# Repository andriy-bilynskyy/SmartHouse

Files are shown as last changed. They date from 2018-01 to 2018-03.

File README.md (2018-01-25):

# Water leaks motinoring system

## System overview
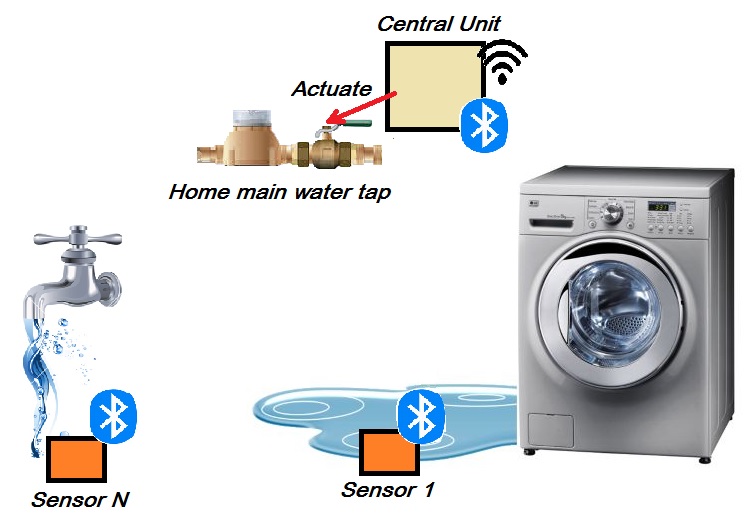
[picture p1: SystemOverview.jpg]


## Features
* Easy integration: The system can be easy integrated into existing environment, no additional wires and pipes replacements.
* Flexible configuration: The system can support different count of water leak sensors, it's easy to add or remove water leak sensor during runtime operation.
* User friendly interface: The system is using simple web interface for configuration and monitoring.
* Non-volatile operation: The system can work without electricity due to backup power supply.
* Low power consumption: Due to used technologies the system use low electricity
* No high voltage: All system components are working with safe 12 volts power supply.
* New technologies: BLE sensors, WI-FI access, WEB user interface.

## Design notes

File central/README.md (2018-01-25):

## Central unit

### HW specification

|Item |Type |Count|Seller link |
|---|---|-----|---|
|MCU unit |Raspberry Pi 3 model B |1 |[original raspberry pi 3 model b](https://www.aliexpress.com/item/In-stock-2015-New-Original-Raspberry-Pi-2-Model-B-1GB-RAM-900Mhz-Quad-Core-ARM/32475849620.html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) |
|SD card |THN-M401S0160E2 |1 |[Toshiba Excerial Pro microSDHC](https://rozetka.com.ua/tshba_microsdhc_pro_16gb_c10_m401s0160e2/p15933949/) |
|Motor driver |board module L298 |1 |[L298N motor driver](https://www.aliexpress.com/item/Special-promotions-5pcs-lot-L298N-motor-driver-board-module-L298-for-arduino-stepper-motor-smart-car/1827893830.html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) |
|5V DC-DC |USB Charge DC-DC Step-down |1 |[USB Charge DC-DC Step-down](https://www.aliexpress.com/item/DC-6V-40V-To-5V-3A-Double-USB-Charge-DC-DC-Step-down-Converter-Module/32664778995.html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,searchweb201602_1_10152_10170_10065_10151_10068_10326_10084_10083_10080_10307_10082_10081_10110_10137_10111_10060_10112_10113_10155_10114_10154_10056_10055_10054_10312_10313_10059_10314_10315_100031_10099_10078_10079_10103_10073_10102_10052_10053_10142_10107_10050_10051-10052_10110,searchweb201603_3,ppcSwitch_5&btsid=f8e5297e-bf45-4b2f-9ce3-2039edf0a898&algo_expid=a3243491-fae2-42a2-a977-101cb692e6c8-0&algo_pvid=a3243491-fae2-42a2-a977-101cb692e6c8&transAbTest=ae803_3) |
|Valve actuator |Yongkang Black Color DN20/DN25|1 |[Yongkang Black Color](https://www.aliexpress.com/item/Yongkang-Black-Color-DN15-LPG-Gas-Valve-Water-Valve-for-Automatic-Shut-Off/32779379748.html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) |
|Backup PSU |Lithium Ion battery pack |1 |[Lithium Ion battery pack](https://www.aliexpress.com/item/Portable-Super-Rechargeable-Lithium-Ion-battery-pack-capacity-DC-12-V-6800-Mah-CCTV-Cam-Monitor/32692388612.html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) |
|Box |--- |1 |--- |
|Wires |--- |---  |--- |

#### HW connection
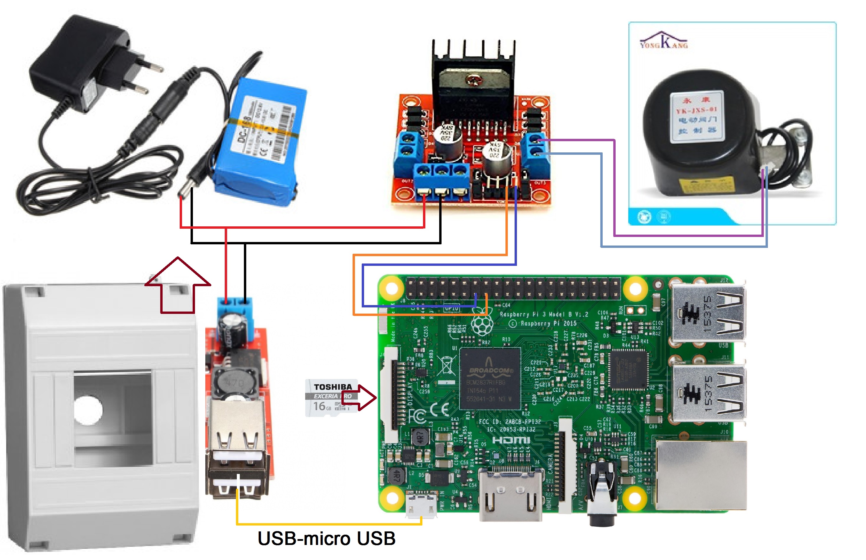
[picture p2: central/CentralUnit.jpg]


## Raspberry PI preparation
### Upgrade raspberry
    sudo apt-get update
    sudo apt-get dist-upgrade
### Setup WIFI
    sudo nano /etc/network/interfaces

    auto lo
    iface lo inet loopback

    auto wlan0
    iface wlan0 inet static
    address 192.168.0.10
    netmask 255.255.255.0
    gateway 192.168.0.1
    wpa-essid ap_name
    wpa-psk ap_pass
    
### Clone repository to home folder on Raspberry Pi
    sudo apt-get install git
    ssh-keygen -t rsa
    git clone git@github.com:andriy-bilynskyy/SmartHouse.git 
### Install Apache
    sudo apt-get install apache2
### Install SQL
    sudo apt-get install mysql-server
### Install PHP
    sudo apt-get install php5 libapache2-mod-php5 php5-mysql    
### Relocate Apache html content 
    sudo /etc/init.d/apache2 stop
    sudo rm -R html/
    sudo ln -s /home/pi/SmartHouse/central/www/ /var/www/html
    sudo /etc/init.d/apache2 start
### Install Bluetooth
    sudo apt-get install bluetooth bluez
    
### NGINX (optional instead of appache)
 
	sudo apt-get install nginx
	sudo apt-get install php5-fpm
	sudo nano /etc/nginx/sites-enabled/default

	index index.php index.html index.htm;

	# pass the PHP scripts to FastCGI server listening on 127.0.0.1:9000
	#
	location ~ \.php$ {
		include snippets/fastcgi-php.conf;

		# With php5-cgi alone:
	#       fastcgi_pass 127.0.0.1:9000;
		# With php5-fpm:
		fastcgi_pass unix:/var/run/php5-fpm.sock;
	}

	sudo /etc/init.d/nginx reload
	sudo /etc/init.d/nginx start

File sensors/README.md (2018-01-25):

## Water leak sensor ADC front-end
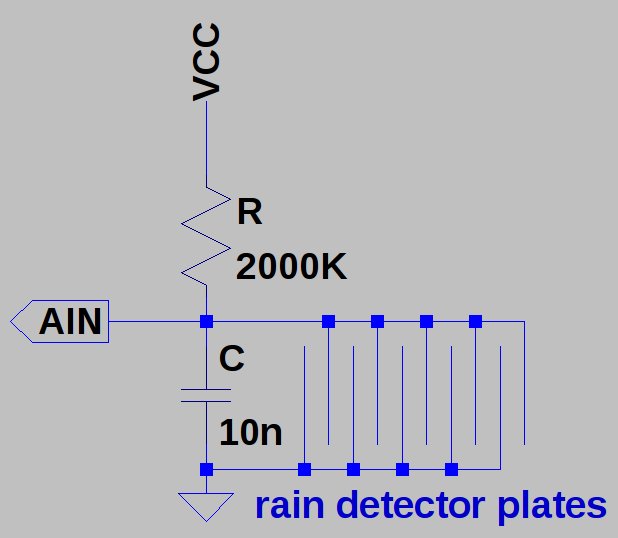
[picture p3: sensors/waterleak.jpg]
 
## Debug the system

edit the file
ble_sensors/src/sdk_config.h
	#define NRF_LOG_ENABLED 0
set value to 1

	JLinkRTTClient
	
	JLinkExe -device nrf51822 -speed 1000 -if swd
	r
	g

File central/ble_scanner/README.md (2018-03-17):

## Bluetooth low energy sensors scanner
This part of software monitors available bluetooth LE sensors.
And updates the information about them and theirs state.
#### Compile executable
source files location: *central/ble_scanner*
necessarily libraries:
- libmysqlclient-dev
- libbluetooth-dev

	make
#### Insatallation
	sudo cp ble_scanner_serv /etc/init.d/
	sudo update-rc.d ble_scanner_serv defaults
#### Usage
	sudo /etc/init.d/ble_scanner status
	sudo /etc/init.d/ble_scanner start
	sudo /etc/init.d/ble_scanner stop
	sudo /etc/init.d/ble_scanner restart

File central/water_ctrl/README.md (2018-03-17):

## Water valve control service
This part of software analyzes state of subscribed water leak sensors.
Based on this information it controls the water valve.
#### Compile executable
source files location: *central/water_valve_ctrl*
necessarily libraries:
- libmysqlclient-dev
- [Wiring Pi](http://wiringpi.com/examples/quick2wire-and-wiringpi/install-and-testing/)

	make
#### Insatallation
	sudo cp valve_ctrl_serv /etc/init.d/
	sudo update-rc.d valve_ctrl_serv defaults
#### Usage
	sudo /etc/init.d/valve_ctrl status
	sudo /etc/init.d/valve_ctrl start
	sudo /etc/init.d/valve_ctrl stop
	sudo /etc/init.d/valve_ctrl restart

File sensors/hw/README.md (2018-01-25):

[PCB manufacture](https://www.elecrow.com/10pcs-2-layer-pcb.html)

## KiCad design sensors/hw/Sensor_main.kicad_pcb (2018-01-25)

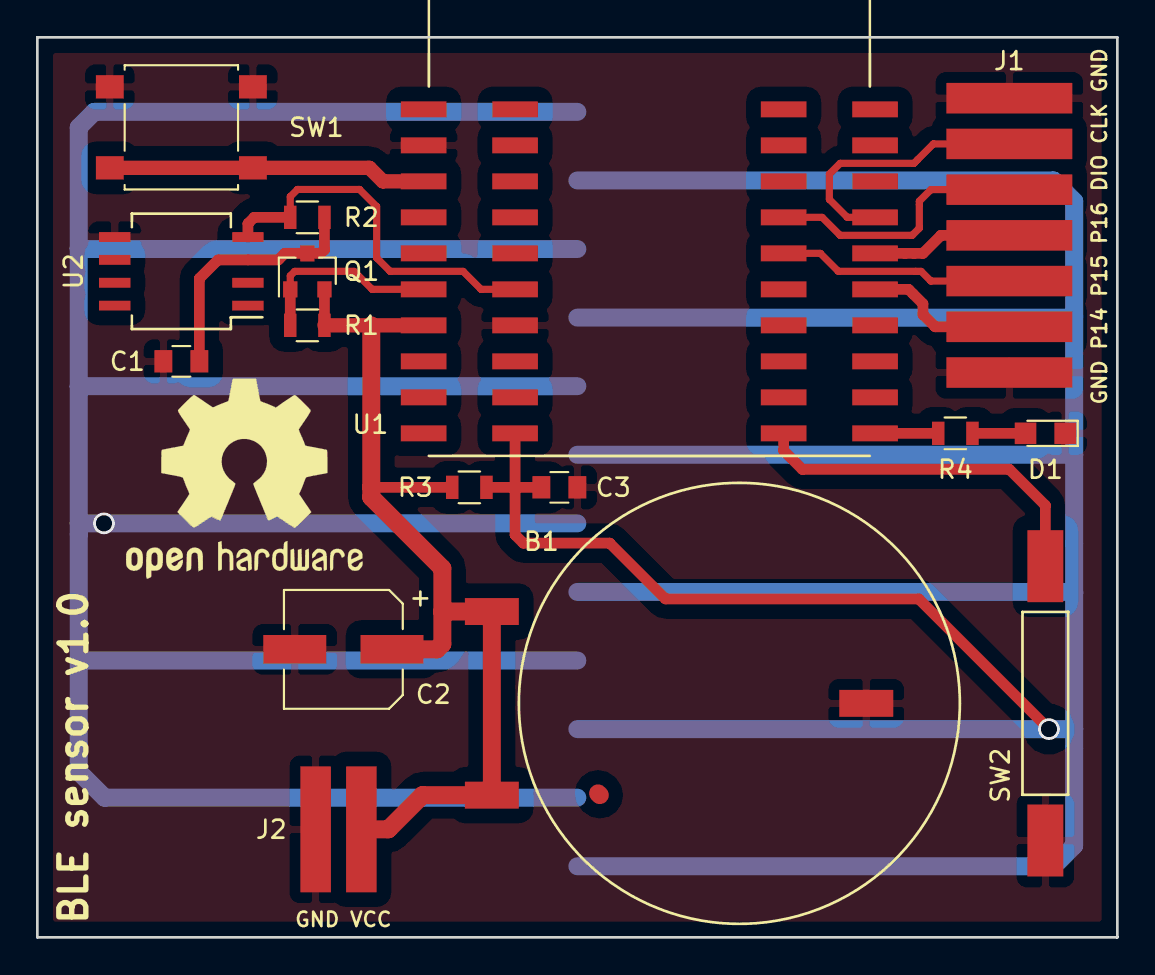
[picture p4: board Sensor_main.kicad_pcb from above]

Board: 2 copper layers, 60.0 x 50.0 mm, 17 parts (1 on the bottom side), 15 nets.

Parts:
B1: CR2477
C1: 100n; C_0805
C2: 220u (RC)6,3*7,7; CP_Elec_6.3x7.7
C3: 10n; C_0805
D1: FYLS-0805GD; LED_0805
J1: ZL211-07KG; ZL211-07G
J2: ZL211-02KG; ZL201-02G
Q1: IRLML6401; SOT-23
R1: 47K; R_0805
R2: 4.7K; R_0805
R3: 2M; R_0805
R4: 270R; R_0805
SW1: B3FS-1000P; SW_SPST_B3S-1000
SW2: KA-80
U1: NRF51822_Eval
U2: DS18B20; SO-8_5.3x6.2mm_Pitch1.27mm
U3: WATER_SENSOR

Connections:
/1WIRE: R2.2, U1.10, U2.4
/AIN: C3.1, R3.2, U1.18, U3.1
/CLK: J1.2, U1.32
/DIO: J1.3, U1.31
/P14: J1.6, U1.28
/P15: J1.5, U1.29
/P16: J1.4, U1.30
/PON#: Q1.1, R1.2, U1.9
GND: B1.2, C1.2, C2.2, C3.2, D1.1, J1.1, J1.7, J2.2, SW1.1, SW2.2, U1.1, U1.12, U2.5, U3.2
unnamed: C1.1, Q1.3, R2.1, U2.3
unnamed: D1.2, R4.1
unnamed: R4.2, U1.20
unnamed: SW1.2, U1.3
unnamed: SW2.1, U1.19
VCC: B1.1, C2.1, J2.1, Q1.2, R1.1, R3.1, U1.11

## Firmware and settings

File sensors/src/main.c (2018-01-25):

#include <stdbool.h>
#include <stdint.h>
#include <ble_advdata.h>
#include <nordic_common.h>
#include <softdevice_handler.h>
#include <nrf_log.h>
#include <nrf_log_ctrl.h>
#include <ble_gap.h>
#include <app_timer.h>
#include <nrf_gpio.h>
#include <nrf_drv_adc.h>
#include "sensor.h"


#define KEY_INPUT                       22 // Sensor key input P22
#define LED_OUTPUT                       6 // Sensor key input P06

void assert_nrf_callback(uint16_t line_num, const uint8_t * p_file_name)
{
    app_error_handler(0xDEADBEEF, line_num, p_file_name);
}

static void ble_stack_init(void)
{
    nrf_clock_lf_cfg_t clock_lf_cfg = {.source = NRF_CLOCK_LF_SRC_XTAL, .rc_ctiv = 0, .rc_temp_ctiv  = 0, .xtal_accuracy = NRF_CLOCK_LF_XTAL_ACCURACY_20_PPM};
    SOFTDEVICE_HANDLER_INIT(&clock_lf_cfg, NULL);
    ble_enable_params_t ble_enable_params;
    APP_ERROR_CHECK(softdevice_enable_get_default_config(0, 0, &ble_enable_params));
    CHECK_RAM_START_ADDR(0, 0);
    APP_ERROR_CHECK(softdevice_enable(&ble_enable_params));
}

static const char * sensor_name = NULL;

void sensor_set_name(const char * name)
{
    sensor_name = name;
}

static nrf_adc_value_t adc_vcc_values[10] = {0};

static void update_vcc_value(void)
{
    static bool inited = false;
    static size_t pointer = 0;

    static const nrf_drv_adc_channel_t cfg = {{{.resolution = NRF_ADC_CONFIG_RES_10BIT, 
                                                .input = ADC_CONFIG_INPSEL_SupplyOneThirdPrescaling,
                                                .reference = NRF_ADC_CONFIG_REF_VBG,
                                                .ain = NRF_ADC_CONFIG_INPUT_DISABLED
                                              }}, NULL
                                             };
    nrf_adc_value_t value = 0;
    APP_ERROR_CHECK(nrf_drv_adc_sample_convert(&cfg, &value));
    if(!inited)
    {
        inited = true;
        for(size_t i = 0; i < sizeof(adc_vcc_values)/sizeof(nrf_adc_value_t); i++)
        {
            adc_vcc_values[i] = value;
        }
        pointer = 0;
    }
    else
    {
        adc_vcc_values[pointer++] = value;
        if(pointer >= sizeof(adc_vcc_values)/sizeof(nrf_adc_value_t))
        {
            pointer = 0;
        }
    }
}

static nrf_adc_value_t get_vcc_value(void)
{
    size_t sum = 0;
    for(size_t i = 0; i < sizeof(adc_vcc_values)/sizeof(nrf_adc_value_t); i++)
    {
        sum += adc_vcc_values[i];
    }
    return sum/(sizeof(adc_vcc_values)/sizeof(nrf_adc_value_t));
}

void sensor_advertise(const char * value)
{
    if(sensor_name && value)
    {
        static const char sensor_id[] = "sensor";
        size_t sensor_str_len = strlen(sensor_id) + strlen(sensor_name) + strlen(value) + 7;

        char sensor_str[sensor_str_len + 1];
        size_t cur_len = 0;
        strcpy(&sensor_str[cur_len], sensor_id);
        cur_len += strlen(sensor_str);
        sensor_str[cur_len] = ' ';
        strcpy(&sensor_str[cur_len + 1], sensor_name);
        cur_len = strlen(sensor_str);
        sensor_str[cur_len] = ' ';
        uint32_t vcc = 360u * get_vcc_value() / 1024u;
        sensor_str[cur_len + 1] = '0' + (vcc /100u) % 10u;
        sensor_str[cur_len + 2] = '.';
        sensor_str[cur_len + 3] = '0' + (vcc /10u) % 10u;
        sensor_str[cur_len + 4] = '0' + vcc % 10u;
        sensor_str[cur_len + 5] = ' ';
        strcpy(&sensor_str[cur_len + 6], value);

        NRF_LOG_INFO("Sensor data[%d]: %s\r\n",sensor_str_len,nrf_log_push(sensor_str));
        if(sensor_str_len > 24)
        {
            NRF_LOG_INFO("Advertisement data too long! Cut to 24 bytes.\r\n");
            sensor_str_len = 24;
        }

        ble_advdata_manuf_data_t manuf_specific_data;
        manuf_specific_data.data.p_data = (uint8_t *)sensor_str;
        manuf_specific_data.data.size   = sensor_str_len;
        manuf_specific_data.company_identifier = 0x0059;

        ble_advdata_t advdata;
        memset(&advdata, 0, sizeof(advdata));

        advdata.name_type             = BLE_ADVDATA_NO_NAME;
        advdata.flags                 = BLE_GAP_ADV_FLAG_BR_EDR_NOT_SUPPORTED;
        advdata.p_manuf_specific_data = &manuf_specific_data;

        APP_ERROR_CHECK(ble_advdata_set(&advdata, NULL));
        //APP_ERROR_CHECK(sd_ble_gap_tx_power_set(4));
        ble_gap_adv_params_t adv_params;
        memset(&adv_params, 0, sizeof(adv_params));

        adv_params.type        = BLE_GAP_ADV_TYPE_ADV_NONCONN_IND;
        adv_params.p_peer_addr = NULL;                             // Undirected advertisement.
        adv_params.fp          = BLE_GAP_ADV_FP_ANY;
        adv_params.interval    = MSEC_TO_UNITS(100, UNIT_0_625_MS);
        adv_params.timeout     = 0;

        APP_ERROR_CHECK(sd_ble_gap_adv_start(&adv_params));
    }
}

#if NRF_LOG_ENABLED == 1
static void reverse_array(uint8_t buf[], uint16_t len)
{
    for(uint8_t i = 0; i < len/2; i++)
    {
        uint8_t tmp = buf[len - i - 1];
        buf[len - i - 1] = buf[i];
        buf[i] = tmp;
    }
}
#endif

void sensor_led_on(void)
{
    nrf_gpio_cfg_output(LED_OUTPUT);
    nrf_gpio_pin_set(LED_OUTPUT);
}

void sensor_led_off(void)
{
    nrf_gpio_cfg_default(LED_OUTPUT);
    nrf_gpio_pin_clear(LED_OUTPUT);
}

//each 0.5 Second
static void on_wake_up(void * p_context)
{
    NRF_LOG_INFO("Wake up...\r\n");
    (void)sd_ble_gap_adv_stop();
    (void)p_context;
    static uint32_t vcc_cnt = 0;
    if(!vcc_cnt)
    {
        update_vcc_value();
        vcc_cnt = 10;
    }
    else
    {
        vcc_cnt --;
    }
    static bool force_update = true;
    if(nrf_gpio_pin_read(KEY_INPUT))
    {
        sensor_led_off();
        routine_sensor(force_update);
        force_update = false;
    }
    else
    {
        sensor_led_on();
        sensor_advertise("key");
        force_update = true;
    } 
}

int main(void)
{
    APP_ERROR_CHECK(NRF_LOG_INIT(NULL));
    ble_stack_init();

    #if NRF_LOG_ENABLED == 1
    ble_gap_addr_t ble_addr;
    ret_code_t ret_code = sd_ble_gap_address_get(&ble_addr);
    if(ret_code == NRF_SUCCESS)
    {
        reverse_array(ble_addr.addr, BLE_GAP_ADDR_LEN);
        NRF_LOG_HEXDUMP_INFO(ble_addr.addr, BLE_GAP_ADDR_LEN);
    }
    else
    {
        NRF_LOG_INFO("Get address error!\r\n");
    }
    #endif

    start_sensor();

    nrf_gpio_cfg_input(KEY_INPUT, NRF_GPIO_PIN_PULLUP);
    
    nrf_drv_adc_config_t config = NRF_DRV_ADC_DEFAULT_CONFIG;
    APP_ERROR_CHECK(nrf_drv_adc_init(&config, NULL));

    APP_TIMER_INIT(0, 4, false);
    APP_TIMER_DEF(apptimer_id);
    APP_ERROR_CHECK(app_timer_create(&apptimer_id, APP_TIMER_MODE_REPEATED, on_wake_up));
    APP_ERROR_CHECK(app_timer_start(apptimer_id, APP_TIMER_TICKS(500, 0), NULL));
    NRF_LOG_INFO("Sensor init done!\r\n");

    for (;;)
    {
        if (NRF_LOG_PROCESS() == false)
        {
            APP_ERROR_CHECK(sd_app_evt_wait());
        }
    }
}

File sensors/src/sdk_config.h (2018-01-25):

#ifndef SDK_CONFIG_H
#define SDK_CONFIG_H
// <<< Use Configuration Wizard in Context Menu >>>\n
#ifdef USE_APP_CONFIG
#include "app_config.h"
#endif
// <h> nRF_BLE 

//==========================================================
// <q> BLE_ADVERTISING_ENABLED  - ble_advertising - Advertising module
 

#ifndef BLE_ADVERTISING_ENABLED
#define BLE_ADVERTISING_ENABLED 0
#endif

// <q> BLE_DTM_ENABLED  - ble_dtm - Module for testing RF/PHY using DTM commands
 

#ifndef BLE_DTM_ENABLED
#define BLE_DTM_ENABLED 0
#endif

// <q> BLE_RACP_ENABLED  - ble_racp - Record Access Control Point library
 

#ifndef BLE_RACP_ENABLED
#define BLE_RACP_ENABLED 0
#endif

// <q> NRF_BLE_QWR_ENABLED  - nrf_ble_qwr - Queued writes support module (prepare/execute write)
 

#ifndef NRF_BLE_QWR_ENABLED
#define NRF_BLE_QWR_ENABLED 0
#endif

// <q> PEER_MANAGER_ENABLED  - peer_manager - Peer Manager
 

#ifndef PEER_MANAGER_ENABLED
#define PEER_MANAGER_ENABLED 0
#endif

// </h> 
//==========================================================

// <h> nRF_BLE_Services 

//==========================================================
// <q> BLE_ANCS_C_ENABLED  - ble_ancs_c - Apple Notification Service Client
 

#ifndef BLE_ANCS_C_ENABLED
#define BLE_ANCS_C_ENABLED 0
#endif

// <q> BLE_ANS_C_ENABLED  - ble_ans_c - Alert Notification Service Client
 

#ifndef BLE_ANS_C_ENABLED
#define BLE_ANS_C_ENABLED 0
#endif

// <q> BLE_BAS_C_ENABLED  - ble_bas_c - Battery Service Client
 

#ifndef BLE_BAS_C_ENABLED
#define BLE_BAS_C_ENABLED 0
#endif

// <q> BLE_BAS_ENABLED  - ble_bas - Battery Service
 

#ifndef BLE_BAS_ENABLED
#define BLE_BAS_ENABLED 0
#endif

// <q> BLE_CSCS_ENABLED  - ble_cscs - Cycling Speed and Cadence Service
 

#ifndef BLE_CSCS_ENABLED
#define BLE_CSCS_ENABLED 0
#endif

// <q> BLE_CTS_C_ENABLED  - ble_cts_c - Current Time Service Client
 

#ifndef BLE_CTS_C_ENABLED
#define BLE_CTS_C_ENABLED 0
#endif

// <q> BLE_DIS_ENABLED  - ble_dis - Device Information Service
 

#ifndef BLE_DIS_ENABLED
#define BLE_DIS_ENABLED 0
#endif

// <q> BLE_GLS_ENABLED  - ble_gls - Glucose Service
 

#ifndef BLE_GLS_ENABLED
#define BLE_GLS_ENABLED 0
#endif

// <q> BLE_HIDS_ENABLED  - ble_hids - Human Interface Device Service
 

#ifndef BLE_HIDS_ENABLED
#define BLE_HIDS_ENABLED 0
#endif

// <e> BLE_HRS_C_ENABLED - ble_hrs_c - Heart Rate Service Client
//==========================================================
#ifndef BLE_HRS_C_ENABLED
#define BLE_HRS_C_ENABLED 0
#endif
#if  BLE_HRS_C_ENABLED
// <o> BLE_HRS_C_RR_INTERVALS_MAX_CNT - Maximum number of RR_INTERVALS per notification to be decoded 
#ifndef BLE_HRS_C_RR_INTERVALS_MAX_CNT
#define BLE_HRS_C_RR_INTERVALS_MAX_CNT 30
#endif

#endif //BLE_HRS_C_ENABLED
// </e>

// <q> BLE_HRS_ENABLED  - ble_hrs - Heart Rate Service
 

#ifndef BLE_HRS_ENABLED
#define BLE_HRS_ENABLED 0
#endif

// <q> BLE_HTS_ENABLED  - ble_hts - Health Thermometer Service
 

#ifndef BLE_HTS_ENABLED
#define BLE_HTS_ENABLED 0
#endif

// <q> BLE_IAS_C_ENABLED  - ble_ias_c - Immediate Alert Service Client
 

#ifndef BLE_IAS_C_ENABLED
#define BLE_IAS_C_ENABLED 0
#endif

// <q> BLE_IAS_ENABLED  - ble_ias - Immediate Alert Service
 

#ifndef BLE_IAS_ENABLED
#define BLE_IAS_ENABLED 0
#endif

// <q> BLE_LBS_C_ENABLED  - ble_lbs_c - Nordic LED Button Service Client
 

#ifndef BLE_LBS_C_ENABLED
#define BLE_LBS_C_ENABLED 0
#endif

// <q> BLE_LBS_ENABLED  - ble_lbs - LED Button Service
 

#ifndef BLE_LBS_ENABLED
#define BLE_LBS_ENABLED 0
#endif

// <q> BLE_LLS_ENABLED  - ble_lls - Link Loss Service
 

#ifndef BLE_LLS_ENABLED
#define BLE_LLS_ENABLED 0
#endif

// <q> BLE_NUS_C_ENABLED  - ble_nus_c - Nordic UART Central Service
 

#ifndef BLE_NUS_C_ENABLED
#define BLE_NUS_C_ENABLED 0
#endif

// <q> BLE_NUS_ENABLED  - ble_nus - Nordic UART Service
 

#ifndef BLE_NUS_ENABLED
#define BLE_NUS_ENABLED 0
#endif

// <q> BLE_RSCS_C_ENABLED  - ble_rscs_c - Running Speed and Cadence Client
 

#ifndef BLE_RSCS_C_ENABLED
#define BLE_RSCS_C_ENABLED 0
#endif

// <q> BLE_RSCS_ENABLED  - ble_rscs - Running Speed and Cadence Service
 

#ifndef BLE_RSCS_ENABLED
#define BLE_RSCS_ENABLED 0
#endif

// <q> BLE_TPS_ENABLED  - ble_tps - TX Power Service
 

#ifndef BLE_TPS_ENABLED
#define BLE_TPS_ENABLED 0
#endif

// </h> 
//==========================================================

// <h> nRF_Drivers 

//==========================================================
// <e> ADC_ENABLED - nrf_drv_adc - Driver for ADC peripheral (nRF51)
//==========================================================
#ifndef ADC_ENABLED
#define ADC_ENABLED 1
#endif
#if  ADC_ENABLED
// <o> ADC_CONFIG_IRQ_PRIORITY  - Interrupt priority
 

// <i> Priorities 0,2 (nRF51) and 0,1,4,5 (nRF52) are reserved for SoftDevice
// <0=> 0 (highest) 
// <1=> 1 
// <2=> 2 
// <3=> 3 

#ifndef ADC_CONFIG_IRQ_PRIORITY
#define ADC_CONFIG_IRQ_PRIORITY 3
#endif
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

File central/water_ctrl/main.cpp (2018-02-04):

#include "CValveCtrl.h"
#include <CDBHandler.h>
#include <safeout.h>
#include <signal.h>
#include <unistd.h>

void intHandler(int dummy)
{
    static_cast<void>(dummy);
    CValveCtrl::m_terminate = true;
}

int main(void)
{
    dbg::sout.setDbgLevel(dbg::DBG_DEBUG); // (dbg::DBG_INFO);
    dbg::sout << dbg::warn << "Water valve control started" << dbg::endl;
    static_cast<void>(signal(SIGINT, intHandler));
    static_cast<void>(signal(SIGHUP, intHandler));
    static_cast<void>(signal(SIGQUIT, intHandler));
    static_cast<void>(signal(SIGTSTP, intHandler));
    static_cast<void>(signal(SIGTERM, intHandler));
    CDBHandler db;
    db.add_log("WATER VALVE", "Water valve control started.");
    CValveCtrl valve;
    while(!CValveCtrl::m_terminate)
    {
        if(!db.check_water_fault(db.get_water_valve()))
        {
            if(db.get_water_valve())
            {
                db.set_water_valve(false);
                dbg::sout << dbg::warn << "Water closed because of fault" << dbg::endl;
                db.add_log("WATER VALVE", "Water closed because of fault.");
            }
        }
        valve.turn(db.get_water_valve());
        if(db.need_water_scheduled_turn())
        {
            dbg::sout << dbg::warn << "Need schedule turn" << dbg::endl;
            if(db.get_water_valve())
            {
                db.set_water_valve(false);
                valve.turn(false);
                dbg::sout << dbg::warn << "Water closed because of schedule" << dbg::endl;
                db.add_log("WATER VALVE", "Water closed because of schedule.");
                sleep(10);
                db.set_water_valve(true);
                valve.turn(true);
                dbg::sout << dbg::warn << "Water opened because of schedule" << dbg::endl;
                db.add_log("WATER VALVE", "Water opened because of schedule.");
                sleep(10);
            }
        }
        else
        {
            sleep(1);
        }
    }
    static_cast<void>(signal(SIGINT, SIG_DFL));
    static_cast<void>(signal(SIGHUP, SIG_DFL));
    static_cast<void>(signal(SIGQUIT, SIG_DFL));
    static_cast<void>(signal(SIGTSTP, SIG_DFL));
    static_cast<void>(signal(SIGTERM, SIG_DFL));
    dbg::sout << dbg::warn << "Water valve control stopped" << dbg::endl;
    db.add_log("WATER VALVE", "Water valve control stopped.");
    return 0;
}

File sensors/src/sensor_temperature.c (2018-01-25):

#include "sensor.h"
#include <nrf_log.h>
#include <app_error.h>
#include <nrf_gpio.h>
#include <nrf_delay.h>

#define SENSOR_PIN                       29 // DS18B20 data pin
#define POWER_PIN                        28 // DS18B20 power enable pin


void start_sensor(void)
{
    sensor_set_name("temp");
    NRF_LOG_INFO("Sensor started!\r\n");
}

static bool powerState = false;             // power off

static inline void power_on(void)
{
    nrf_gpio_cfg_output(POWER_PIN);
    nrf_gpio_pin_clear(POWER_PIN);
    nrf_delay_us(400);
    powerState = true;
}

static inline void power_off(void)
{
    nrf_gpio_cfg_default(POWER_PIN);
    nrf_gpio_pin_clear(POWER_PIN);
    powerState = false;
}

static inline void therm_input_mode(void)
{
    nrf_gpio_cfg_input(SENSOR_PIN, NRF_GPIO_PIN_NOPULL);
}

static inline void therm_output_mode(void)
{
    nrf_gpio_cfg_output(SENSOR_PIN);
}

static inline void therm_low(void)
{
    nrf_gpio_pin_clear(SENSOR_PIN);
}

static inline void therm_high(void)
{
    nrf_gpio_pin_set(SENSOR_PIN);
}

static inline uint8_t therm_read(void)
{
    return nrf_gpio_pin_read(SENSOR_PIN);
}

static inline bool therm_reset(void)
{
    bool result;
    therm_low();
    therm_output_mode();
    nrf_delay_us(480);
    therm_input_mode();
    nrf_delay_us(60);
    result = therm_read();
    nrf_delay_us(420);
    return !result;
}
 
static inline void therm_write_bit(uint8_t bit)
{
    therm_low();
    therm_output_mode();
    nrf_delay_us(1);
    if(bit) therm_input_mode();
    nrf_delay_us(60);
    therm_input_mode();
}
 
static inline uint8_t therm_read_bit(void)
{
    uint8_t bit = 0;
    therm_low();
    therm_output_mode();
    nrf_delay_us(1);
    therm_input_mode();
    nrf_delay_us(14);
    if(therm_read()) bit = 1;
    nrf_delay_us(45);
    return bit;
}
 
static uint8_t therm_read_byte(void)
{
    uint8_t i = 8, n = 0;
    while(i--)
    {
        n >>= 1;
        n |= (therm_read_bit() << 7);
    }
    return n;
}
 
static void therm_write_byte(uint8_t byte)
{
    uint8_t i = 8;
    while(i--)
    {
        therm_write_bit(byte & 1);
        byte >>= 1;
    }
}

static bool therm_start_convert(void)
{
    bool conv_started = false;
 
    if(therm_reset())
    {
        therm_write_byte(0xCC);
        therm_write_byte(0x44);
        conv_started = true;
    }
 
    return conv_started;
}

static inline bool term_ready(void)
{
    return therm_read_bit();
}

static bool therm_read_temperature(int16_t * temperature)
{
    bool data_avail = false;
    uint8_t temp[2] = {0};
    
    if(therm_reset())
    {
        therm_write_byte(0xCC);
        therm_write_byte(0xBE);
 
        temp[0] = therm_read_byte();
        temp[1] = therm_read_byte();
        if(therm_reset())
        {
            *temperature =  ((((uint16_t)temp[1] << 8) | temp[0]) * 10) / 16; 
            data_avail = true;
        }
    }
 
    return data_avail;
}

static char * temperature_str(int16_t t, char * str)
{
    uint8_t neg = 0, len = 0;
    if(t < 0)
    {
        neg = 1;
        t = -t;
        str[0] = '-';
        len = 1;

    }
    uint8_t rem = t % 10;
    t /= 10;
    do
    {
        uint8_t i = 0;
        for(i = len; i > neg; i--)
        {
            str[i] = str[i - 1];
        }
        str[neg] = '0' + t % 10;
        len ++;
        t /= 10;
    }while(t > 0);
    str[len] = '.';
    str[len + 1] = '0' + rem;
    str[len + 2] = '\0';
    return str;
}

void routine_sensor(bool force_update)
{
    static uint32_t timer_adv = 0;

    if(powerState)
    {
        if(term_ready())
        {
            int16_t temperature = 0;
            if(therm_read_temperature(&temperature))
            {
                char buf[10];
                sensor_advertise(temperature_str(temperature, buf));
            }
            else
            {
                sensor_advertise("error");
            }
            power_off();    
        }
        else if(timer_adv < 2 * 60 * 10 - 2)
        {
            timer_adv --;
            sensor_advertise("error");
            power_off();
        }
    }
    else if(!timer_adv || force_update)
    {
        timer_adv = 2 * 60 * 10;
        NRF_LOG_INFO("Timer %u\r\n", timer_adv);

        power_on();
        if(!therm_start_convert())
        {
            sensor_advertise("error");
            power_off();
        }
    }
    else
    {
        timer_adv --;
    }
}

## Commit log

2018-01-25 Initial commit.
    [Sensor_main.kicad_pcb, Sensor_main.sch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]
2018-01-25 Fixed sensor timediff.
2018-02-03 Fixed SQL request. (subscribe waterleak sensor)
